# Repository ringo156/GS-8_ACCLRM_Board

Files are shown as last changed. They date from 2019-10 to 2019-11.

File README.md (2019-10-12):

# GS-8_ACCLRM_Board

High range accelerometer board for GS-8

Master project -> [project-arrows/GS-8](https://github.com/project-arrows/GS-8)

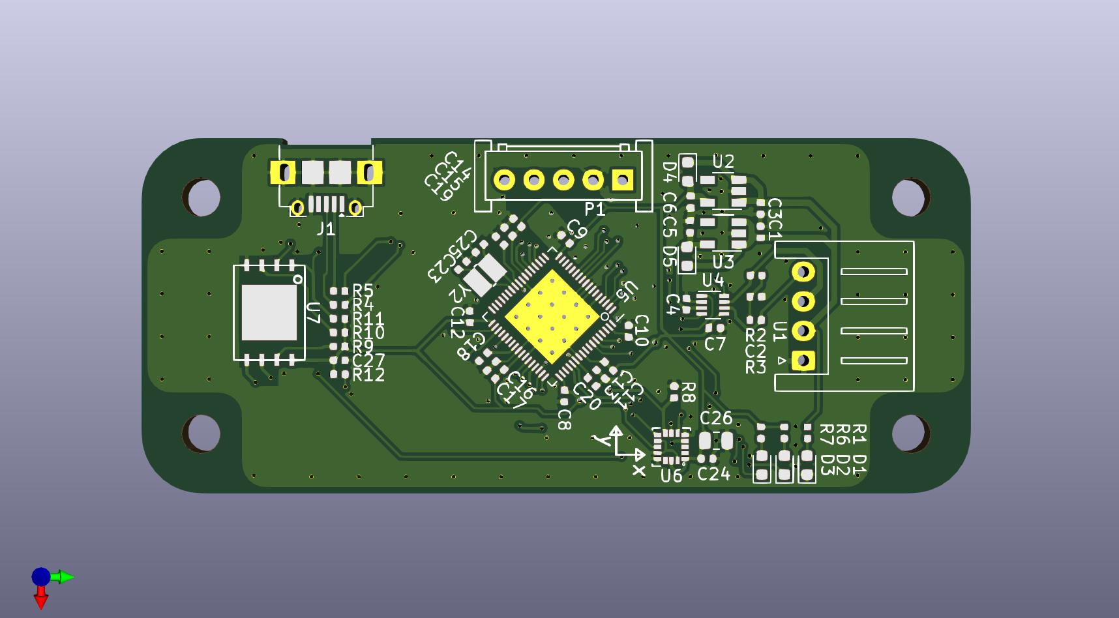
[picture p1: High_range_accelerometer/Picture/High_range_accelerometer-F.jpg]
circut-F


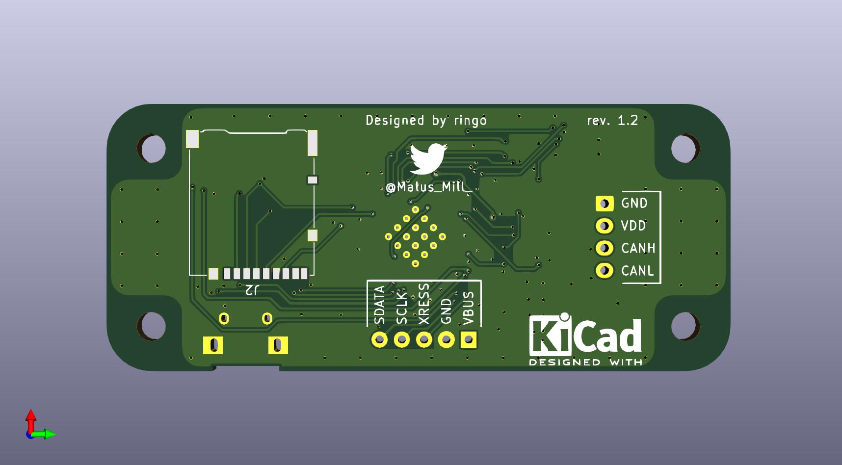
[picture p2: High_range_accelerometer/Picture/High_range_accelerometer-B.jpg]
circuit-B


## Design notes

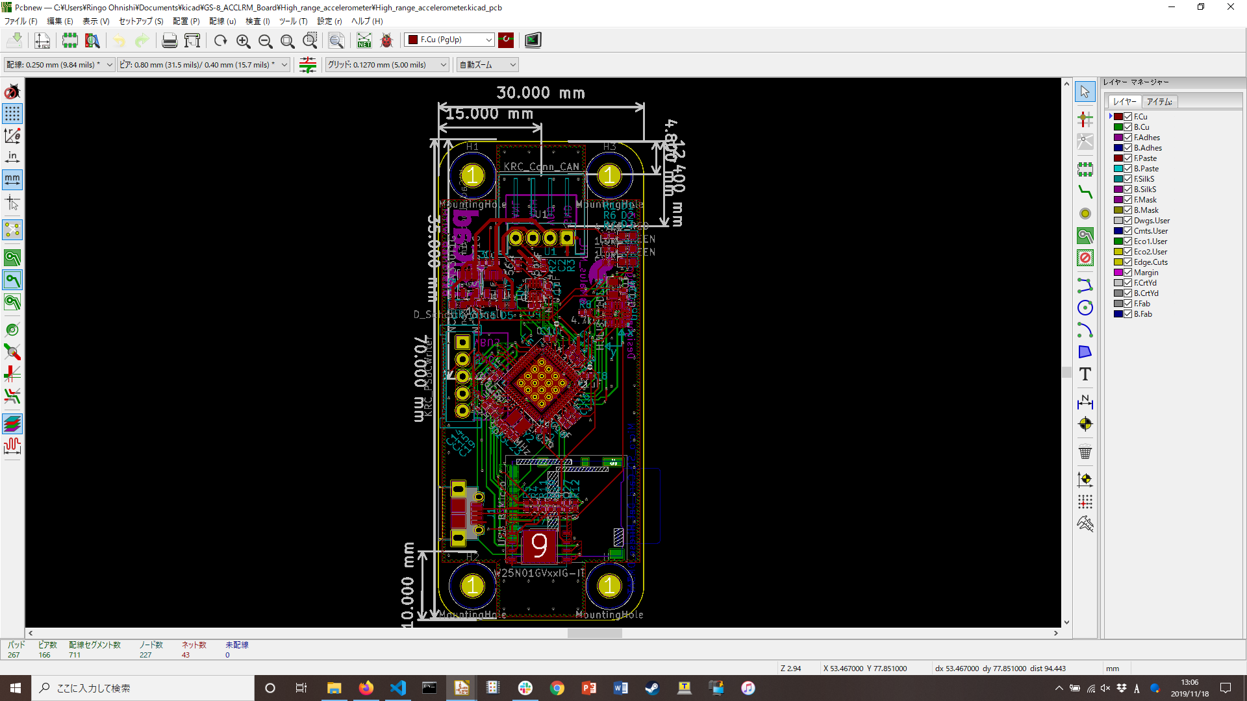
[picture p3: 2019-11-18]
High_range_accelerometer/Picture/スクリーンショット 2019-11-18 13.06.21.png

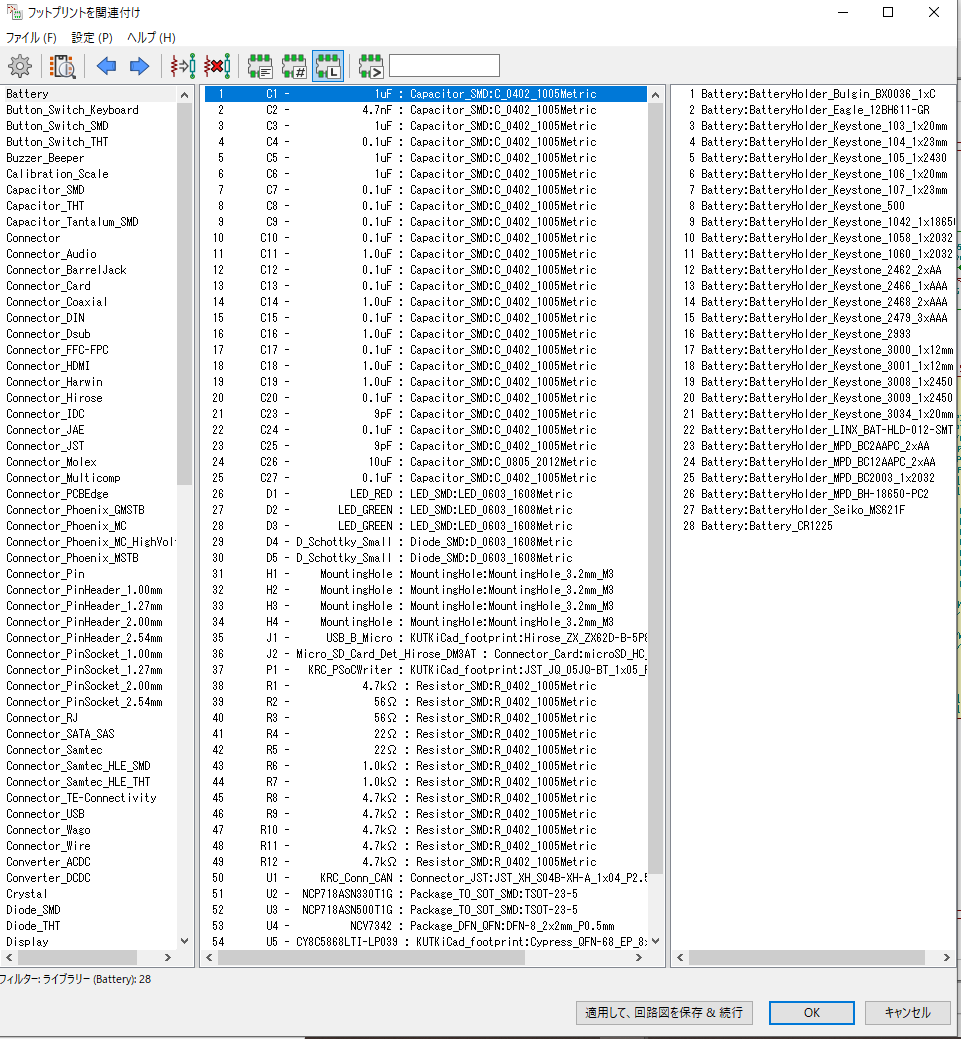
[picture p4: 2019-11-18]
High_range_accelerometer/Picture/スクリーンショット 2019-11-18 13.06.08.png

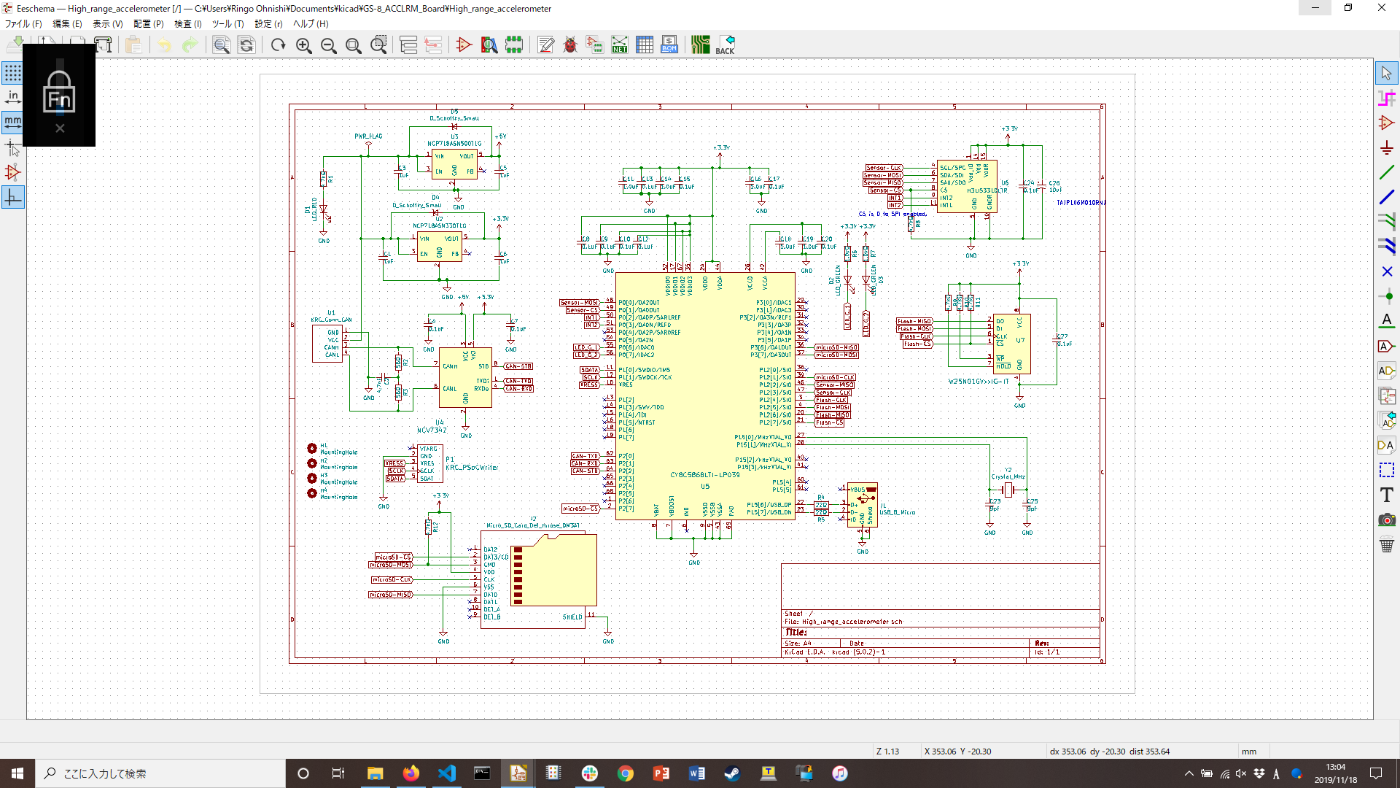
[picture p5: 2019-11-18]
High_range_accelerometer/Picture/スクリーンショット 2019-11-18 13.04.33.png

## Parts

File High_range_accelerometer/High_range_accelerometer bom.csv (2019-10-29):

Source: | C:\Users\Ringo Ohnishi\Documents\kicad\GS-8\High_range_accelerometer\High_range_accelerometer.sch
Date: | 2019/10/15 12:51:46
Tool: | Eeschema (5.0.2)-1
Generator: | C:\Program Files\KiCad\bin\scripting\plugins/bom_csv_grouped_by_value.py
Component Count: | 57
Individual Components:
Item | Qty | Reference(s) | Value | LibPart | Footprint | Datasheet
 |  | C1 | 1uF | Device:C_Small | Capacitor_SMD:C_0402_1005Metric | ~
 |  | C2 | 4.7nF | Device:C_Small | Capacitor_SMD:C_0402_1005Metric | ~
 |  | C3 | 1uF | Device:C_Small | Capacitor_SMD:C_0402_1005Metric | ~
 |  | C4 | 0.1uF | Device:C_Small | Capacitor_SMD:C_0402_1005Metric | ~
 |  | C5 | 1uF | Device:C_Small | Capacitor_SMD:C_0402_1005Metric | ~
 |  | C6 | 1uF | Device:C_Small | Capacitor_SMD:C_0402_1005Metric | ~
 |  | C7 | 0.1uF | Device:C_Small | Capacitor_SMD:C_0402_1005Metric | ~
 |  | C8 | 0.1uF | Device:C_Small | Capacitor_SMD:C_0402_1005Metric | ~
 |  | C9 | 0.1uF | Device:C_Small | Capacitor_SMD:C_0402_1005Metric | ~
 |  | C10 | 0.1uF | Device:C_Small | Capacitor_SMD:C_0402_1005Metric | ~
 |  | C11 | 1.0uF | Device:C_Small | Capacitor_SMD:C_0402_1005Metric | ~
 |  | C12 | 0.1uF | Device:C_Small | Capacitor_SMD:C_0402_1005Metric | ~
 |  | C13 | 0.1uF | Device:C_Small | Capacitor_SMD:C_0402_1005Metric | ~
 |  | C14 | 1.0uF | Device:C_Small | Capacitor_SMD:C_0402_1005Metric | ~
 |  | C15 | 0.1uF | Device:C_Small | Capacitor_SMD:C_0402_1005Metric | ~
 |  | C16 | 1.0uF | Device:C_Small | Capacitor_SMD:C_0402_1005Metric | ~
 |  | C17 | 0.1uF | Device:C_Small | Capacitor_SMD:C_0402_1005Metric | ~
 |  | C18 | 1.0uF | Device:C_Small | Capacitor_SMD:C_0402_1005Metric | ~
 |  | C19 | 1.0uF | Device:C_Small | Capacitor_SMD:C_0402_1005Metric | ~
 |  | C20 | 0.1uF | Device:C_Small | Capacitor_SMD:C_0402_1005Metric | ~
 |  | C23 | 9pF | Device:C_Small | Capacitor_SMD:C_0402_1005Metric | ~
 |  | C24 | 0.1uF | Device:C_Small | Capacitor_SMD:C_0402_1005Metric | ~
 |  | C25 | 9pF | Device:C_Small | Capacitor_SMD:C_0402_1005Metric | ~
 |  | C26 | 10uF | Device:CP1_Small | Capacitor_SMD:C_0805_2012Metric | ~
 |  | C27 | 0.1uF | Device:C_Small | Capacitor_SMD:C_0402_1005Metric | ~
 |  | D1 | LED_RED | Device:LED | LED_SMD:LED_0603_1608Metric | ~
 |  | D2 | LED_GREEN | Device:LED | LED_SMD:LED_0603_1608Metric | ~
 |  | D3 | LED_GREEN | Device:LED | LED_SMD:LED_0603_1608Metric | ~
 |  | D4 | D_Schottky_Small | Device:D_Schottky_Small | Diode_SMD:D_0603_1608Metric | ~
 |  | D5 | D_Schottky_Small | Device:D_Schottky_Small | Diode_SMD:D_0603_1608Metric | ~
 |  | H1 | MountingHole | Mechanical:MountingHole | MountingHole:MountingHole_3.2mm_M3 | ~
 |  | H2 | MountingHole | Mechanical:MountingHole | MountingHole:MountingHole_3.2mm_M3 | ~
 |  | H3 | MountingHole | Mechanical:MountingHole | MountingHole:MountingHole_3.2mm_M3 | ~
 |  | H4 | MountingHole | Mechanical:MountingHole | MountingHole:MountingHole_3.2mm_M3 | ~
 |  | J1 | USB_B_Micro | Connector:USB_B_Micro | KUTKiCad_footprint:Hirose_ZX_ZX62D-B-5P8 | ~
 |  | J2 | Micro_SD_Card_Det_Hirose_DM3AT | Connector:Micro_SD_Card_Det_Hirose_DM3AT | Connector_Card:microSD_HC_Hirose_DM3AT-SF-PEJM5 | https://www.hirose.com/product/en/download_file/key_name/DM3/category/Catalog/doc_file_id/49662/?item_id=195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
 |  | P1 | KRC_PSoCWriter | High_range_accelerometer-rescue:KRC_PSoCWriter-KUT_Connector | KUTKiCad_footprint:JST_JQ_05JQ-BT_1x05_P2.5mm_Vertical
 |  | R1 | 4.7kΩ | Device:R | Resistor_SMD:R_0402_1005Metric | ~
 |  | R2 | 56Ω | Device:R | Resistor_SMD:R_0402_1005Metric | ~
 |  | R3 | 56Ω | Device:R | Resistor_SMD:R_0402_1005Metric | ~
 |  | R4 | 22Ω | Device:R | Resistor_SMD:R_0402_1005Metric | ~
 |  | R5 | 22Ω | Device:R | Resistor_SMD:R_0402_1005Metric | ~
 |  | R6 | 1.0kΩ | Device:R | Resistor_SMD:R_0402_1005Metric | ~
 |  | R7 | 1.0kΩ | Device:R | Resistor_SMD:R_0402_1005Metric | ~
 |  | R8 | 4.7kΩ | Device:R | Resistor_SMD:R_0402_1005Metric | ~
 |  | R9 | 4.7kΩ | Device:R | Resistor_SMD:R_0402_1005Metric | ~
 |  | R10 | 4.7kΩ | Device:R | Resistor_SMD:R_0402_1005Metric | ~
 |  | R11 | 4.7kΩ | Device:R | Resistor_SMD:R_0402_1005Metric | ~
 |  | R12 | 4.7kΩ | Device:R | Resistor_SMD:R_0402_1005Metric | ~
 |  | U1 | KRC_Conn_CAN | KUTKiCad_symbol:KRC_Conn_CAN | Connector_JST:JST_XH_S04B-XH-A_1x04_P2.50mm_Horizontal
 |  | U2 | NCP718ASN330T1G | Regulator_Linear:ADP7142AUZJ | Package_TO_SOT_SMD:TSOT-23-5 | http://www.analog.com/media/en/technical-documentation/data-sheets/ADP7142.pdf
 |  | U3 | NCP718ASN500T1G | Regulator_Linear:ADP7142AUZJ | Package_TO_SOT_SMD:TSOT-23-5 | http://www.analog.com/media/en/technical-documentation/data-sheets/ADP7142.pdf
 |  | U4 | NCV7342 | KUTKiCad_symbol:NCV7342 | Package_DFN_QFN:DFN-8_2x2mm_P0.5mm
 |  | U5 | CY8C5868LTI-LP039 | High_range_accelerometer-rescue:CY8C5868LTI-LP039-KUTKiCad_symbol | KUTKiCad_footprint:Cypress_QFN-68_EP_8x8_Pitch0.4mm
 |  | U6 | H3LIS331DLTR | High_range_accelerometer-rescue:H3LIS331DLTR-My_Library | Package_LGA:LGA-16_3x3mm_P0.5mm_LayoutBorder3x5y | https://www.st.com/content/ccc/resource/technical/document/datasheet/3e/48/02/c7/a4/e6/41/bb/DM00053090.pdf/files/DM00053090.pdf/jcr:content/translations/en.D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
 |  | U7 | W25N01GVxxIG-IT | KUTKiCad_symbol:W25N01GVxxIG-IT | KUTKiCad_footprint:WSON-8_8x6mm_P1.27mm
 |  | Y2 | Crystal_MHz | Device:Crystal | KUTKiCad_footprint:Crystal_Murata_XRCHA | ~
Collated Components:
Item | Qty | Reference(s) | Value | LibPart | Footprint | Datasheet
1 | 4 | C1, C3, C5, C6 | 1uF | Device:C_Small | Capacitor_SMD:C_0402_1005Metric | ~
2 | 1 | C2 | 4.7nF | Device:C_Small | Capacitor_SMD:C_0402_1005Metric | ~
3 | 12 | C4, C7, C8, C9, C10, C12, C13, C15, C17, C20, C24, C27 | 0.1uF | Device:C_Small | Capacitor_SMD:C_0402_1005Metric | ~
4 | 5 | C11, C14, C16, C18, C19 | 1.0uF | Device:C_Small | Capacitor_SMD:C_0402_1005Metric | ~
5 | 2 | C23, C25 | 9pF | Device:C_Small | Capacitor_SMD:C_0402_1005Metric | ~
6 | 1 | C26 | 10uF | Device:CP1_Small | Capacitor_SMD:C_0805_2012Metric | ~
7 | 1 | D1 | LED_RED | Device:LED | LED_SMD:LED_0603_1608Metric | ~
8 | 2 | D2, D3 | LED_GREEN | Device:LED | LED_SMD:LED_0603_1608Metric | ~
9 | 2 | D4, D5 | D_Schottky_Small | Device:D_Schottky_Small | Diode_SMD:D_0603_1608Metric | ~
10 | 4 | H1, H2, H3, H4 | MountingHole | Mechanical:MountingHole | MountingHole:MountingHole_3.2mm_M3 | ~
11 | 1 | J1 | USB_B_Micro | Connector:USB_B_Micro | KUTKiCad_footprint:Hirose_ZX_ZX62D-B-5P8 | ~
12 | 1 | J2 | Micro_SD_Card_Det_Hirose_DM3AT | Connector:Micro_SD_Card_Det_Hirose_DM3AT | Connector_Card:microSD_HC_Hirose_DM3AT-SF-PEJM5 | https://www.hirose.com/product/en/download_file/key_name/DM3/category/Catalog/doc_file_id/49662/?item_id=195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
13 | 1 | P1 | KRC_PSoCWriter | High_range_accelerometer-rescue:KRC_PSoCWriter-KUT_Connector | KUTKiCad_footprint:JST_JQ_05JQ-BT_1x05_P2.5mm_Vertical
14 | 6 | R1, R8, R9, R10, R11, R12 | 4.7kΩ | Device:R | Resistor_SMD:R_0402_1005Metric | ~
15 | 2 | R2, R3 | 56Ω | Device:R | Resistor_SMD:R_0402_1005Metric | ~
16 | 2 | R4, R5 | 22Ω | Device:R | Resistor_SMD:R_0402_1005Metric | ~
17 | 2 | R6, R7 | 1.0kΩ | Device:R | Resistor_SMD:R_0402_1005Metric | ~
18 | 1 | U1 | KRC_Conn_CAN | KUTKiCad_symbol:KRC_Conn_CAN | Connector_JST:JST_XH_S04B-XH-A_1x04_P2.50mm_Horizontal
19 | 1 | U2 | NCP718ASN330T1G | Regulator_Linear:ADP7142AUZJ | Package_TO_SOT_SMD:TSOT-23-5 | http://www.analog.com/media/en/technical-documentation/data-sheets/ADP7142.pdf
20 | 1 | U3 | NCP718ASN500T1G | Regulator_Linear:ADP7142AUZJ | Package_TO_SOT_SMD:TSOT-23-5 | http://www.analog.com/media/en/technical-documentation/data-sheets/ADP7142.pdf
21 | 1 | U4 | NCV7342 | KUTKiCad_symbol:NCV7342 | Package_DFN_QFN:DFN-8_2x2mm_P0.5mm
22 | 1 | U5 | CY8C5868LTI-LP039 | High_range_accelerometer-rescue:CY8C5868LTI-LP039-KUTKiCad_symbol | KUTKiCad_footprint:Cypress_QFN-68_EP_8x8_Pitch0.4mm
23 | 1 | U6 | H3LIS331DLTR | High_range_accelerometer-rescue:H3LIS331DLTR-My_Library | Package_LGA:LGA-16_3x3mm_P0.5mm_LayoutBorder3x5y | https://www.st.com/content/ccc/resource/technical/document/datasheet/3e/48/02/c7/a4/e6/41/bb/DM00053090.pdf/files/DM00053090.pdf/jcr:content/translations/en.D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
24 | 1 | U7 | W25N01GVxxIG-IT | KUTKiCad_symbol:W25N01GVxxIG-IT | KUTKiCad_footprint:WSON-8_8x6mm_P1.27mm
25 | 1 | Y2 | Crystal_MHz | Device:Crystal | KUTKiCad_footprint:Crystal_Murata_XRCHA | ~

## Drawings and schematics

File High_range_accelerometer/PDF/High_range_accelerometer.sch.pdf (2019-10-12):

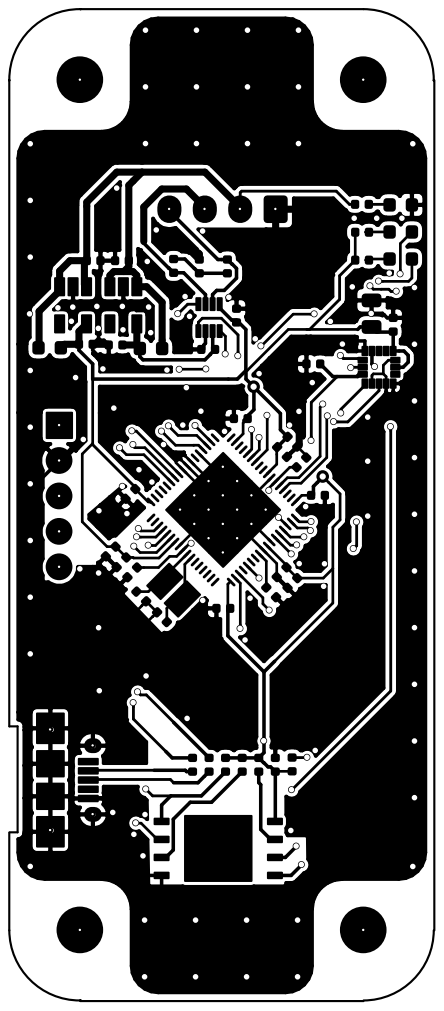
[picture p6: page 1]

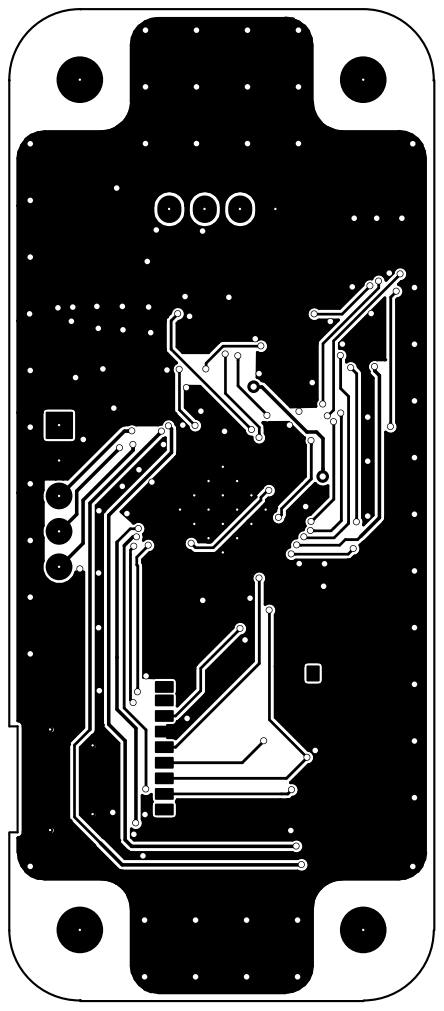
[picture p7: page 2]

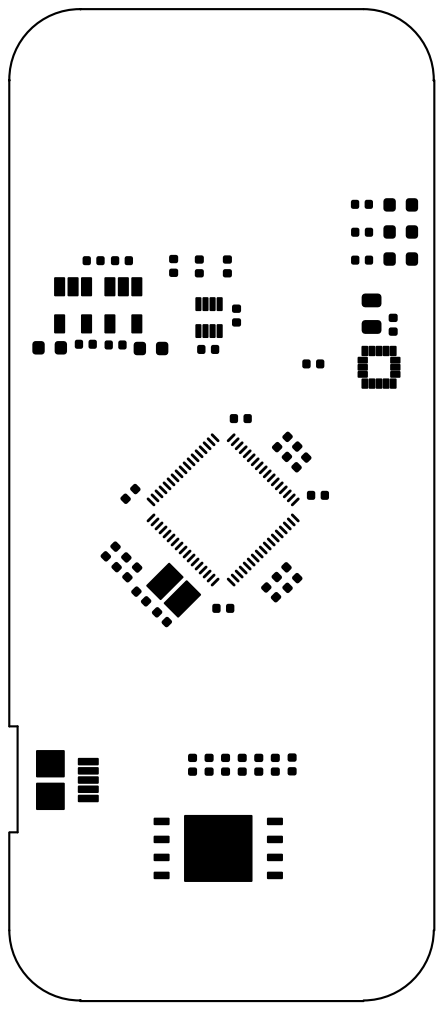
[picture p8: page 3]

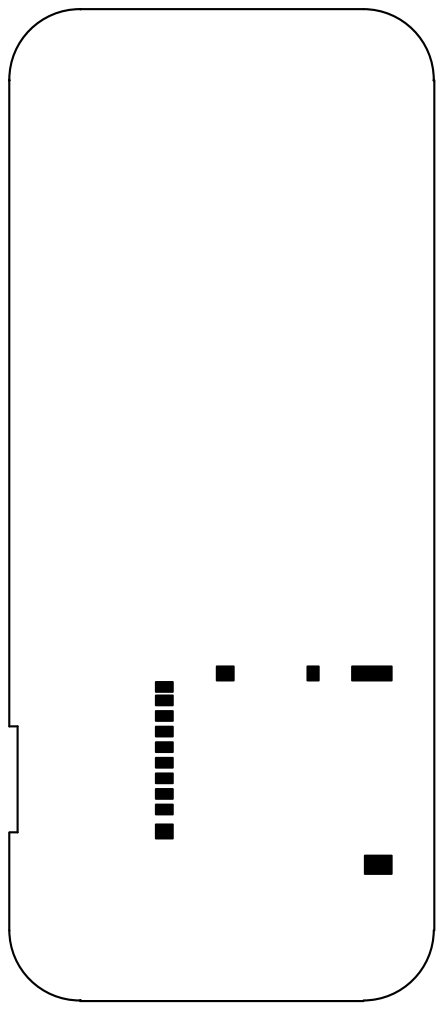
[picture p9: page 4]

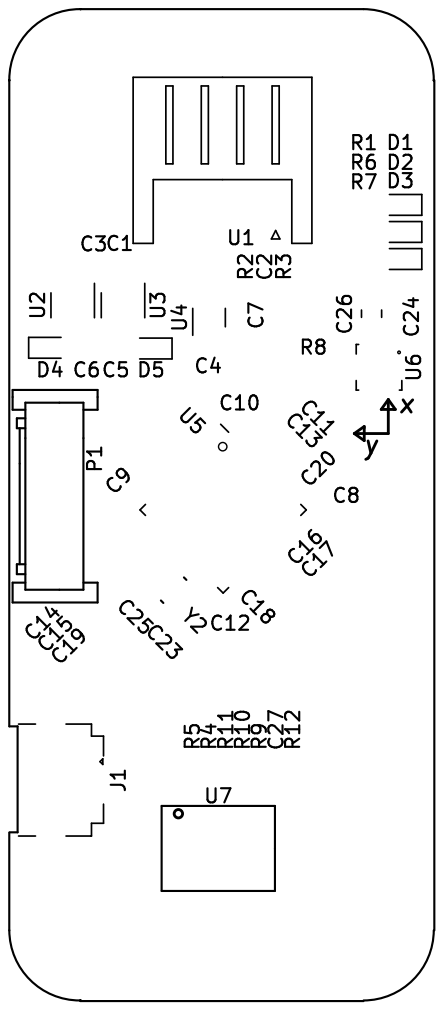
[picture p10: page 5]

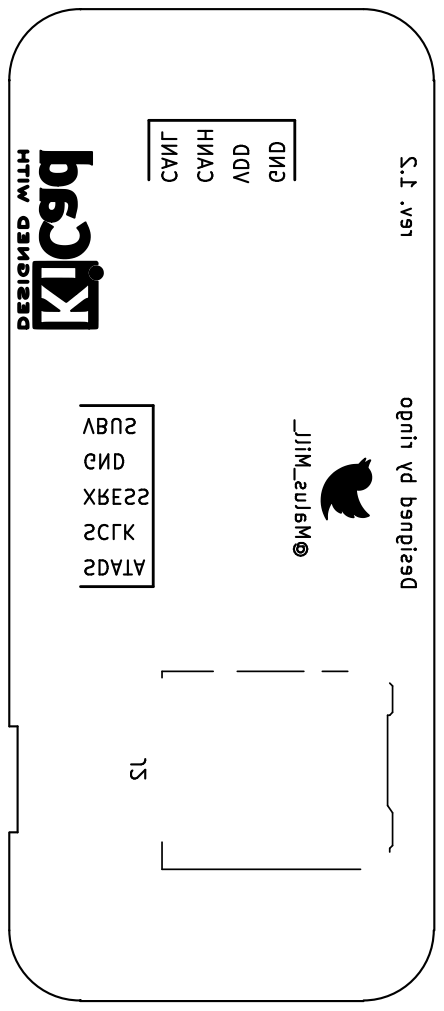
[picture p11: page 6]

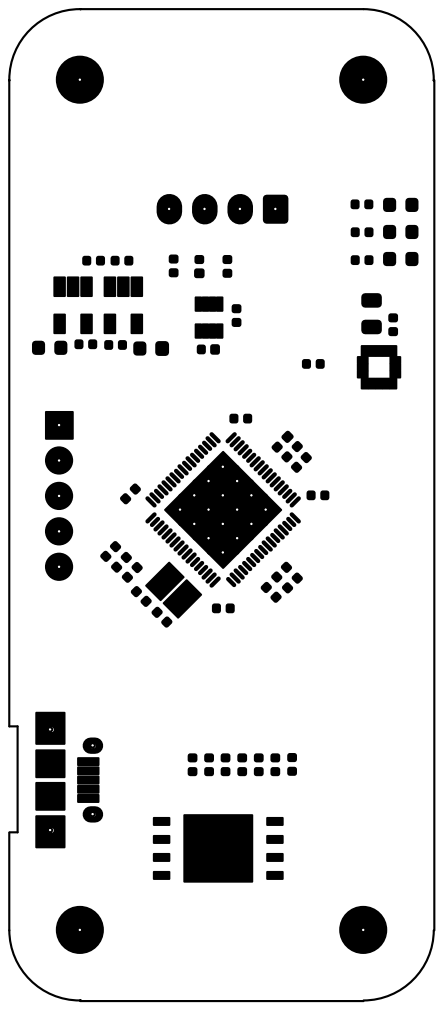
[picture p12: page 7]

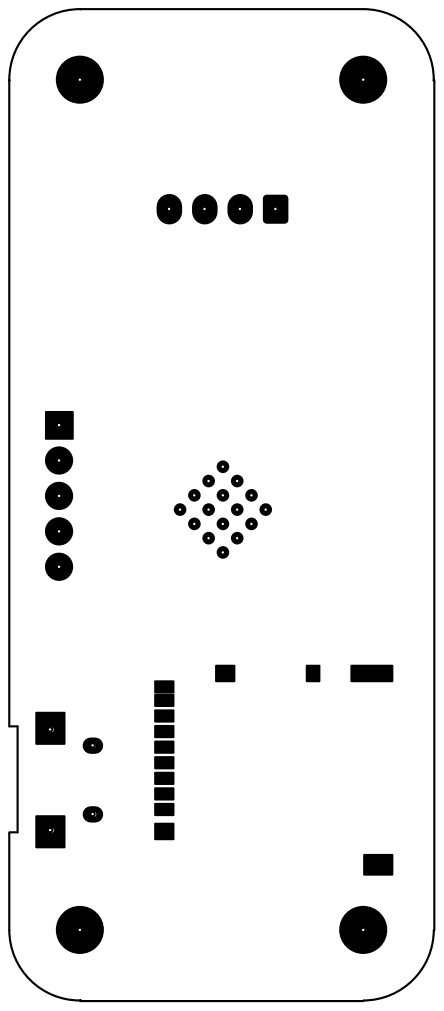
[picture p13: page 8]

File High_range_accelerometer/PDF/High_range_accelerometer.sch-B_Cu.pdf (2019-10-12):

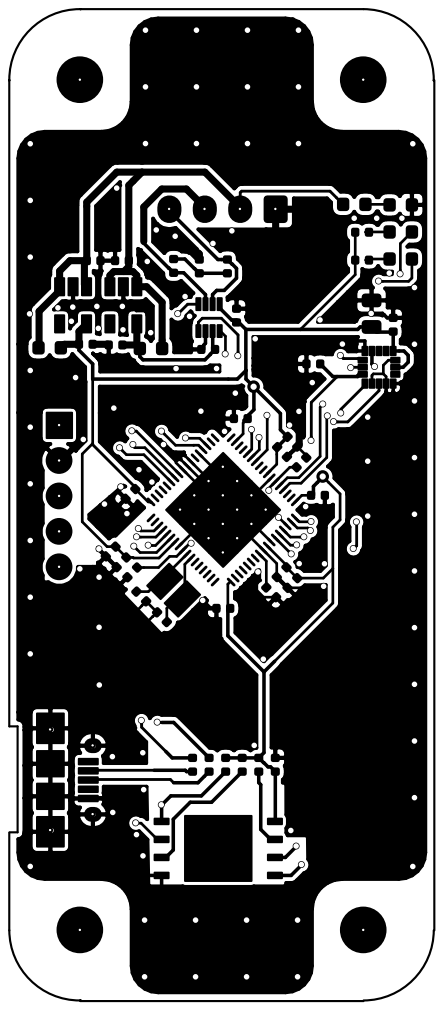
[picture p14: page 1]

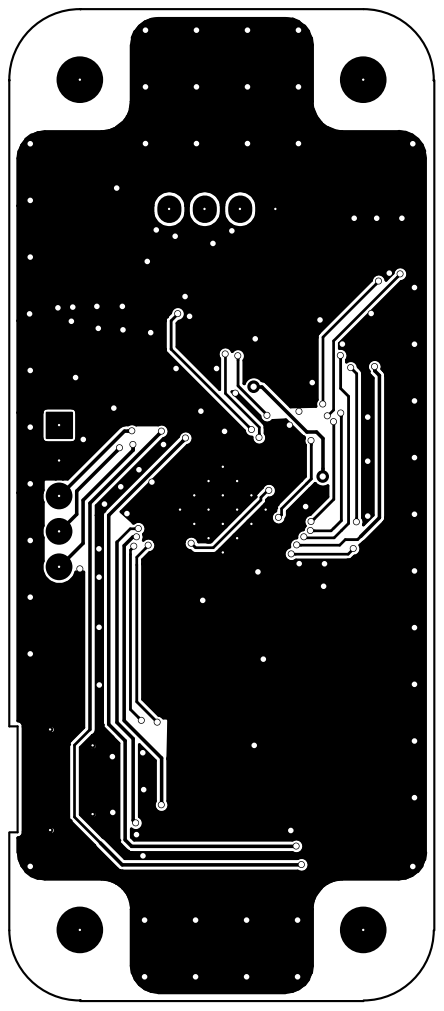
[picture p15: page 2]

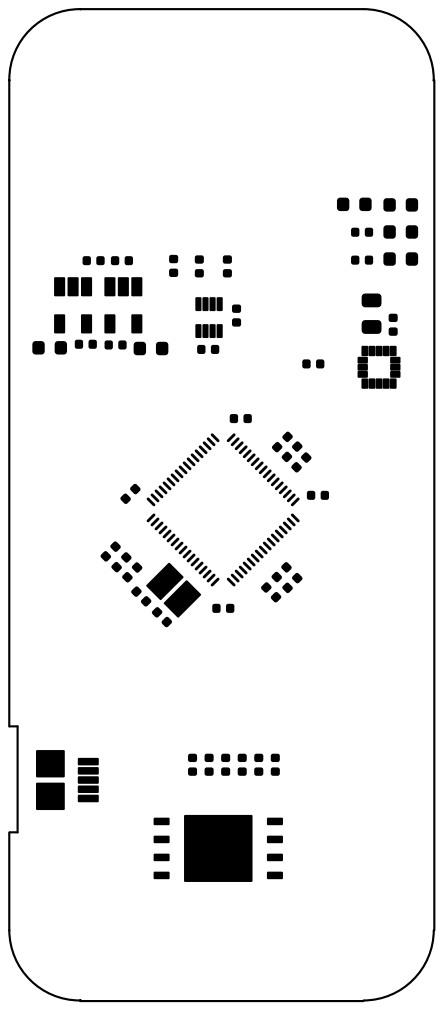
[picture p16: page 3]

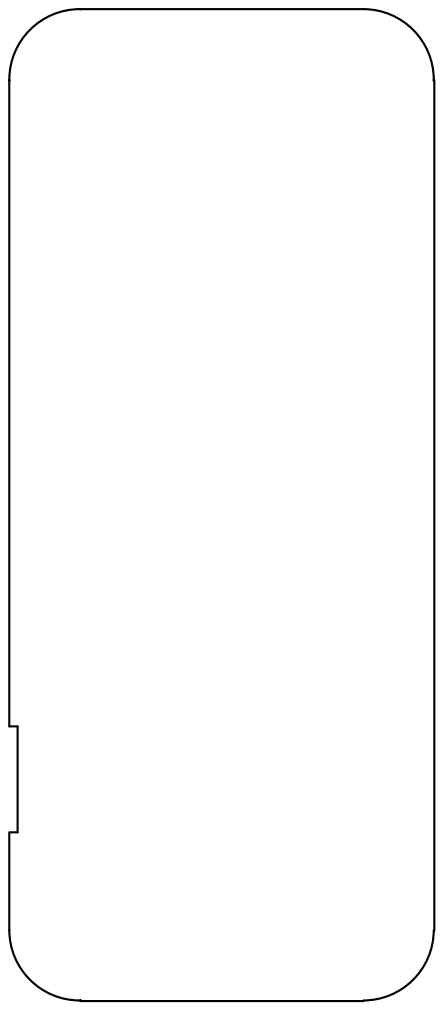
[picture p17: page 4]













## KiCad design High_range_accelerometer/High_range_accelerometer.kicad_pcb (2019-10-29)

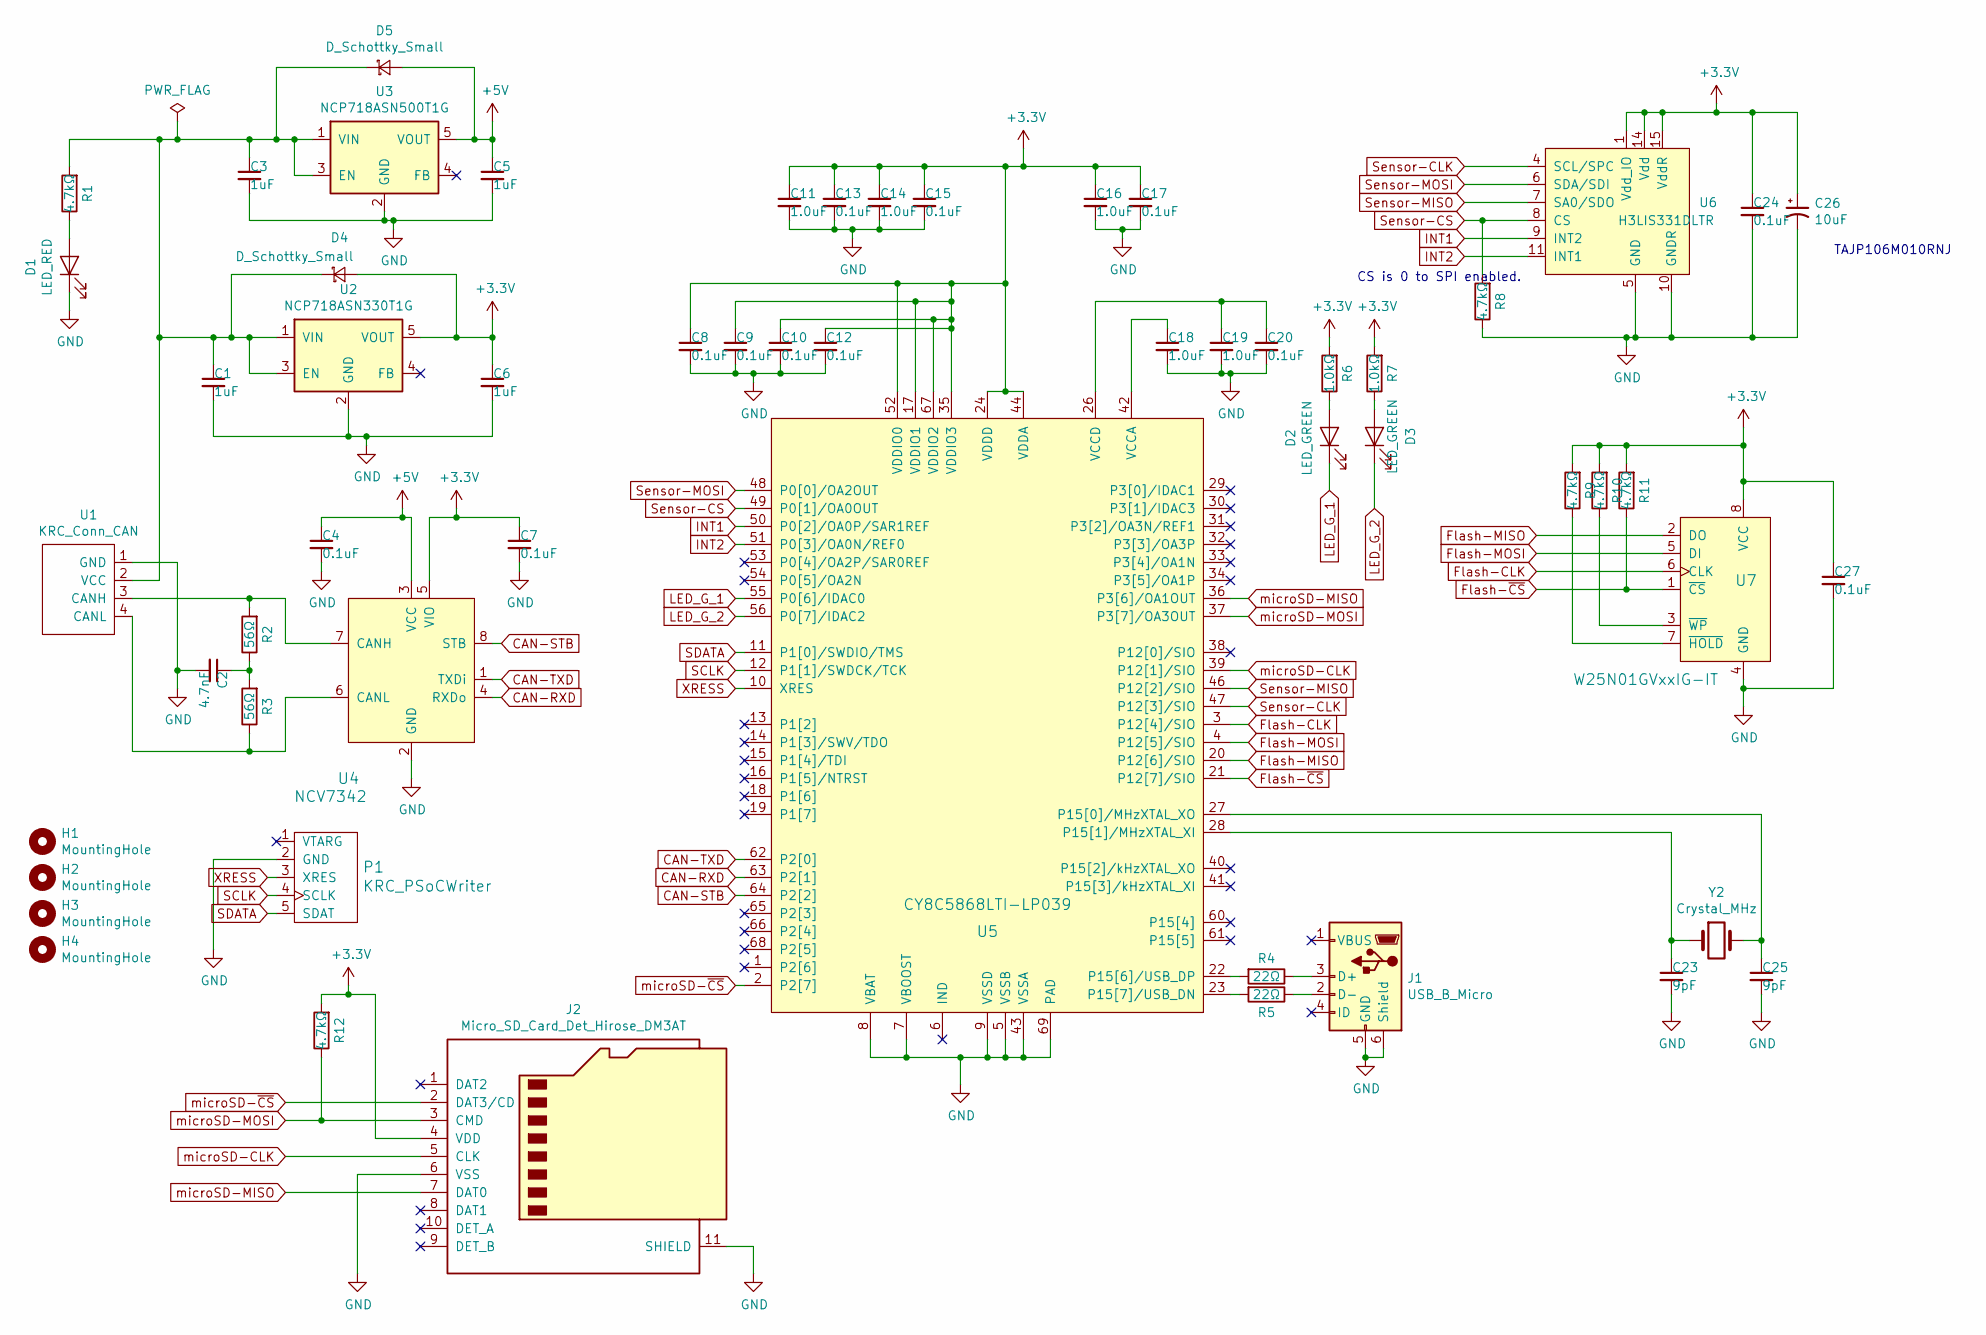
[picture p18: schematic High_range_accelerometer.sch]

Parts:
C1, C3, C5, C6: 1uF; C_0402_1005Metric
C2: 4.7nF; C_0402_1005Metric
C4, C7, C8, C9, C10, C12, C13, C15, C17, C20, C24, C27: 0.1uF; C_0402_1005Metric
C11, C14, C16, C18, C19: 1.0uF; C_0402_1005Metric
C23, C25: 9pF; C_0402_1005Metric
C26: 10uF; C_0805_2012Metric
D1: LED_RED; LED_0603_1608Metric
D2, D3: LED_GREEN; LED_0603_1608Metric
D4, D5: D_Schottky_Small; D_0603_1608Metric
H1, H2, H3, H4: MountingHole; MountingHole_3.2mm_M3
J1: USB_B_Micro; Hirose_ZX_ZX62D-B-5P8
J2: Micro_SD_Card_Det_Hirose_DM3AT; microSD_HC_Hirose_DM3AT-SF-PEJM5
P1: KRC_PSoCWriter; JST_JQ_05JQ-BT_1x05_P2.5mm_Vertical
R1, R8, R9, R10, R11, R12: 4.7kΩ; R_0402_1005Metric
R2, R3: 56Ω; R_0402_1005Metric
R4, R5: 22Ω; R_0402_1005Metric
R6, R7: 1.0kΩ; R_0402_1005Metric
U1: KRC_Conn_CAN; JST_XH_S04B-XH-A_1x04_P2.50mm_Horizontal
U2: NCP718ASN330T1G; TSOT-23-5
U3: NCP718ASN500T1G; TSOT-23-5
U4: NCV7342; DFN-8_2x2mm_P0.5mm
U5: CY8C5868LTI-LP039; Cypress_QFN-68_EP_8x8_Pitch0.4mm
U6: H3LIS331DLTR; LGA-16_3x3mm_P0.5mm_LayoutBorder3x5y_handsoldering
U7: W25N01GVxxIG-IT; WSON-8_8x6mm_P1.27mm
Y2: Crystal_MHz; Crystal_Murata_XRCHA

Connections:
+3V3: C6.1, C7.1, C8.1, C9.1, C10.1, C11.1, C12.1, C13.1, C14.1, C15.1, C16.1, C17.1, C24.1, C26.1, C27.1, D4.2 (A), J2.4 (VDD), R6.2, R7.2, R9.2, R10.2, R11.2, R12.2, U2.5 (VOUT), U4.5 (VIO), U5.17 (VDDIO1), U5.24 (VDDD), U5.35 (VDDIO3), U5.44 (VDDA), U5.52 (VDDIO0), U5.59 (VDDD), U5.67 (VDDIO2), U6.1 (Vdd_IO), U6.14 (Vdd), U6.15 (VddR), U7.8 (VCC)
+5V: C4.1, C5.1, D5.2 (A), U3.5 (VOUT), U4.3 (VCC)
CAN-RXD: U4.4 (RXDo), U5.63 (P2[1])
CAN-STB: U4.8 (STB), U5.64 (P2[2])
CAN-TXD: U4.1 (TXDi), U5.62 (P2[0])
Flash-CLK: U5.3 (P12[4]/SIO), U7.6 (CLK)
Flash-MISO: U5.20 (P12[6]/SIO), U7.2 (DO)
Flash-MOSI: U5.4 (P12[5]/SIO), U7.5 (DI)
Flash-~CS: R11.1, U5.21 (P12[7]/SIO), U7.1 (~CS)
GND: C1.2, C2.2, C3.2, C4.2, C5.2, C6.2, C7.2, C8.2, C9.2, C10.2, C11.2, C12.2, C13.2, C14.2, C15.2, C16.2, C17.2, C18.2, C19.2, C20.2, C23.2, C24.2, C25.2, C26.2, C27.2, D1.1 (K), J1.5 (GND), J1.6 (Shield), J2.6 (VSS), J2.11 (SHIELD), P1.2 (GND), R8.1, U1.1 (GND), U2.2 (GND), U3.2 (GND), U4.2 (GND), U5.5 (VSSB), U5.7 (VBOOST), U5.8 (VBAT), U5.9 (VSSD), U5.25 (VSSD), U5.43 (VSSA), U5.45 (VSSD), U5.58 (VSSD), U5.69 (PAD), U6.5 (GND), U6.10 (GNDR), U6.12 (GND), U6.13 (GND), U6.16 (GND), U7.4 (GND)
INT1: U5.50 (P0[2]/OA0P/SAR1REF), U6.9 (INT2)
INT2: U5.51 (P0[3]/OA0N/REF0), U6.11 (INT1)
LED_G_1: D2.1 (K), U5.55 (P0[6]/IDAC0)
LED_G_2: D3.1 (K), U5.56 (P0[7]/IDAC2)
unnamed: C1.1, C3.1, D4.1 (K), D5.1 (K), R1.2, U1.2 (VCC), U2.1 (VIN), U2.3 (EN), U3.1 (VIN), U3.3 (EN)
unnamed: C2.1, R2.1, R3.2
unnamed: C18.1, U5.42 (VCCA)
unnamed: C19.1, C20.1, U5.26 (VCCD), U5.57 (VCCD)
unnamed: C23.1, U5.28 (P15[1]/MHzXTAL_XI), Y2.1
unnamed: C25.1, U5.27 (P15[0]/MHzXTAL_XO), Y2.2
unnamed: D1.2 (A), R1.1
unnamed: D2.2 (A), R6.1
unnamed: D3.2 (A), R7.1
unnamed: J1.2 (D-), R5.1
unnamed: J1.3 (D+), R4.1
unnamed: R2.2, U1.3 (CANH), U4.7 (CANH)
unnamed: R3.1, U1.4 (CANL), U4.6 (CANL)
unnamed: R4.2, U5.22 (P15[6]/USB_DP)
unnamed: R5.2, U5.23 (P15[7]/USB_DN)
unnamed: R9.1, U7.7 (~HOLD)
unnamed: R10.1, U7.3 (~WP)
SCLK: P1.4 (SCLK), U5.12 (P1[1]/SWDCK/TCK)
SDATA: P1.5 (SDAT), U5.11 (P1[0]/SWDIO/TMS)
Sensor-CLK: U5.47 (P12[3]/SIO), U6.4 (SCL/SPC)
Sensor-CS: R8.2, U5.49 (P0[1]/OA0OUT), U6.8 (CS)
Sensor-MISO: U5.46 (P12[2]/SIO), U6.7 (SA0/SDO)
Sensor-MOSI: U5.48 (P0[0]/OA2OUT), U6.6 (SDA/SDI)
XRESS: P1.3 (XRES), U5.10 (XRES)
microSD-CLK: J2.5 (CLK), U5.39 (P12[1]/SIO)
microSD-MISO: J2.7 (DAT0), U5.36 (P3[6]/OA1OUT)
microSD-MOSI: J2.3 (CMD), R12.1, U5.37 (P3[7]/OA3OUT)
microSD-~CS: J2.2 (DAT3/CD), U5.2 (P2[7])

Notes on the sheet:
CS is 0 to SPI enabled.
TAJP106M010RNJ

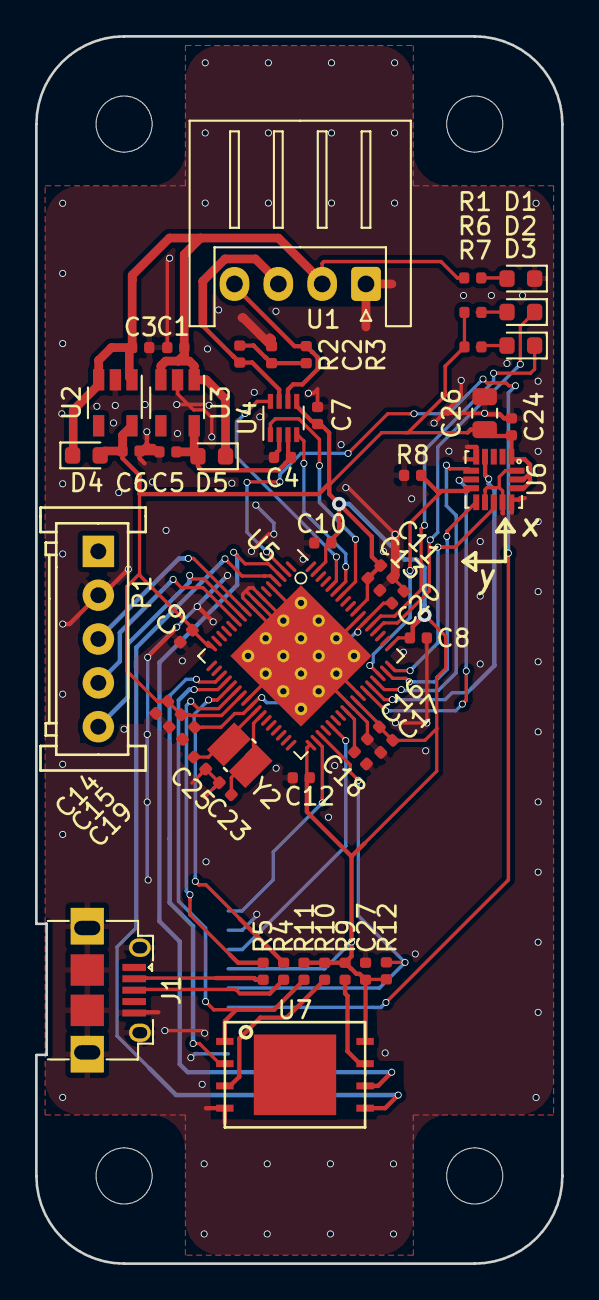
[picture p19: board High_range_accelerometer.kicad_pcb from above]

Board: 2 copper layers, 30.0 x 70.0 mm, 57 parts (1 on the bottom side), 42 nets.

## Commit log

2019-10-08 とりあえずできた
    [High_range_accelerometer.kicad_pcb, High_range_accelerometer.sch]
2019-10-08 change regulator
    [High_range_accelerometer.kicad_pcb, High_range_accelerometer.sch]
2019-10-12 add extension change script for kicad to elecrow
2019-10-12 add SVG and PDF and Gerber files
    [High_range_accelerometer.kicad_pcb, High_range_accelerometer.sch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]
2019-10-12 add sdCard
    [High_range_accelerometer.kicad_pcb, High_range_accelerometer.sch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]
2019-10-12 Typo corrected
    [High_range_accelerometer.GBL, High_range_accelerometer.GBO, High_range_accelerometer.GBS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]
2019-10-29 modified sensor footprint
    [High_range_accelerometer bom.csv, High_range_accelerometer.kicad_pcb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]
